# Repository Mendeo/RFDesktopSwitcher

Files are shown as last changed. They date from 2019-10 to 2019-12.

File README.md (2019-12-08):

# RF Desktop Switcher

Это проект устройства, которое переключает экран рабочего стола в Windows 10 по сигналу с датчика движения. Связь между датчиком движения и компьютером беспроводная.

## Проект включает в себя:
##### Передающая часть
* Схема устройства.
* Печатная плата.
* Прошивка микроконтроллера, управляющего передающей частью.

##### Приёмная чать
* Прошивку Arduino.
* 3D модель корпуса готового устройства, подключаемого к компьютеру.

##### Программное обеспечение
* Программа для Windows 10, которая соединяется с подключенным устройствои и осуществляет по сигналу переключение рабочих столов.
* Эмулятор приёмного устройства (используется для разработки основной программы).

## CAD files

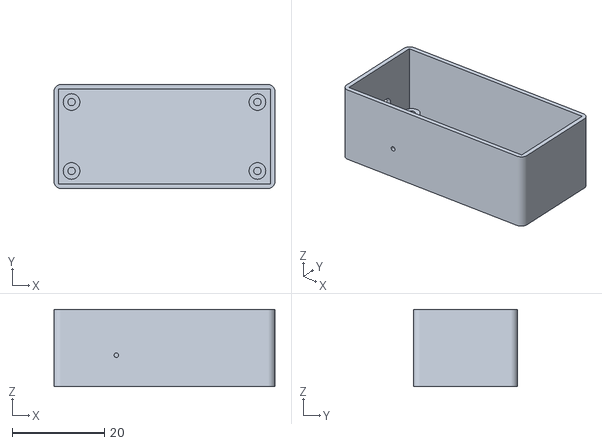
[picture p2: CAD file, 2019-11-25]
RX/Корпус/box.stl
47.8 x 22.5 x 16.7

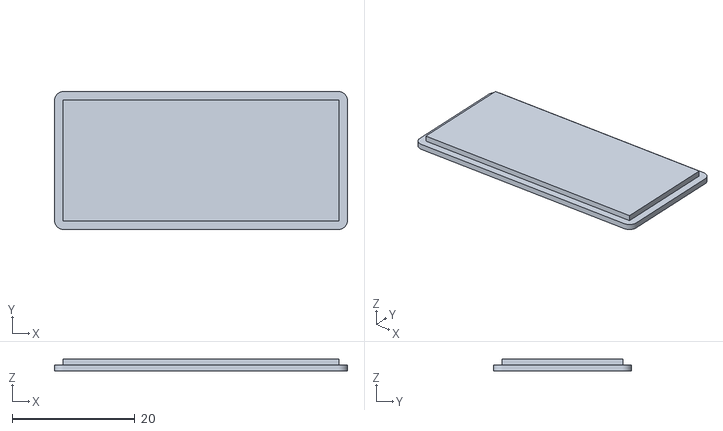
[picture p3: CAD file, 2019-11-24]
RX/Корпус/cap.stl
47.8 x 22.5 x 2.00

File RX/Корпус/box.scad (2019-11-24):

box(100, 70, 30, 2, 5, 2);
translate([25, 15, 0])
pillars(50, 40, 10, 20, 4, 0.8);
*translate([0, 0, 30])
cap(100, 70, 2, 5, 3, 5, 2, 0.4);



module box(L, W, HBox, T, extPinRad, intPinRad, needInternalPins)
{
	difference()
	{
		union()
		{
			difference()
			{
				cube([L, W, HBox]);
				translate([T, T, T])
				cube([L - 2 * T, W - 2 * T, HBox]);
			}
			for (edge = [0 : 3]) pinEdgePlacer(edge, HBox, extPinRad, intPinRad, 0, T, 0, L, W, 0, 0); //Цилиндр по четырём углам
		}
		//Вырез оставшихся треугольников по четырём углам.
		for (edge = [0 : 3]) excessTriangle(edge, HBox, extPinRad, L, W);
		if (!needInternalPins)
		{
			//Вырез внутренних цилиндров по четырём углам.
			for(edge = [0 : 3]) cutInternalPins(edge, HBox, extPinRad, L, W, T);
		}
	}
}

module cap(L, W, T, HCapExt, HCapInt, extPinRad, intPinRad, capGap, boxHasInternalPins)
{
	difference()
	{
		difference()
		{
			union()
			{
				cube([L, W, HCapExt]);
			}
			for (edge = [0 : 3]) pinEdgePlacer(edge, HCapExt, extPinRad, intPinRad, 0, 0, 2, L, W, 0, 0); //Цилиндр по четырём углам
		}
		for (edge = [0 : 3]) excessTriangle(edge, HCapExt, extPinRad, L, W); //Вырез оставшихся треугольников по четырём углам.
	}
	difference()
	{
		translate([T + capGap, T + capGap, -HCapInt]) //Часть крышки, что заходит внутрь.
		cube([L - 2 * (T + capGap), W - 2 * (T + capGap), HCapInt]);
		if (boxHasInternalPins)
		{
			translate([0, 0, -HCapInt])
			for (edge = [0 : 3]) pinEdgePlacer(edge, HCapInt, extPinRad + capGap, 0, 0, 0, 1, L, W, 0, 0);
		}
	}
}

//Размещает пины (цилиндры с дыркой) по 4-м сторонам прямоугольника, заданного width, length, x, y. Угол задаётся edge.
//Размеры прямоугольника соответствуют краям цилиндров с радиусом er.
//Если радиуса er не достаточно, то можно увеличить его добавкой addToExtRad. Это увеличит внешний радиус без смещения центра пина.
module pinEdgePlacer(edge, hh, er, ir, addToExtRad, holeFromBottom, pinSelect, length, width, deltaX, deltaY)
{
	x = (edge == 1 || edge == 3) ? length - er : er;
	y = (edge == 2 || edge == 3) ? width - er : er;
	translate([x + deltaX, y + deltaY, 0])
	pin(pinSelect, er + addToExtRad, ir, hh, holeFromBottom);
}

//Пины для прикручивания (цилиндры с дыркой).
module pin(pinSelect, er, ir, hh, holeFromBottom) //pinSelect: 0 - цилиндр с дыркой, 1 - только цилиндр, 2 - только дырка в виде цилиндра.
{
	difference()
	{
		if (pinSelect == 0 || pinSelect == 1) cylinder(r = er, h = hh);
		if (pinSelect == 0 || pinSelect == 2)
		{
			translate([0, 0, holeFromBottom])
			cylinder(r = ir, h = hh - holeFromBottom);
		}
	}
}

//Вырез оставшихся треугольников по четырём углам.
module excessTriangle(edge, hh, er, L, W)
{
	xCyl = (edge == 1 || edge == 3) ? L - er : er;
	yCyl = (edge == 2 || edge == 3) ? W - er : er;
	xCube = (edge == 1 || edge == 3) ? L - er: 0;
	yCube = (edge == 2 || edge == 3) ? W - er : 0;
	difference()
	{
		translate([xCube, yCube, 0])
		cube([er, er, hh]);
		translate([xCyl, yCyl, 0])
		cylinder(r = er, h = hh);
	}
}

module cutInternalPins(edge, hh, er, L, W, T)
{
	xCube = (edge == 1 || edge == 3) ? L - T - er * 2 : T;
	yCube = (edge == 2 || edge == 3) ? W - T - er * 2 : T;
	translate([xCube, yCube, T])
	cube([er * 2, er * 2, hh]);
}

//Столбики с вырезом - держалки для чего-либо.
module pillar(wPillar, hPillar, hFromPlate, cut)
{
	difference()
	{
		cube([wPillar, wPillar, hPillar]);
		translate([wPillar * (1 - cut), wPillar * (1 - cut), hFromPlate])
		cube([wPillar * cut, wPillar * cut, hPillar - hFromPlate]);
	}
}

//Размещает столбики-держалки по четырём углам.
module pillars(L, W, wPillar, hPillar, hFromPlate, cut) //W - по x ширина, L - по y длина - расстояние между стойками
{
	delta = (1 - cut) * wPillar;
	render()
	for (edge = [0 : 3])
	{
		x = (edge == 1 || edge == 3) ? L + delta : 0 - delta;
		y = (edge == 2 || edge == 3) ? W + delta : 0 - delta;
		alpha = (edge == 0 ? 0 : (edge == 1 ? 90 : (edge == 2 ? -90 : 180)));
		translate([x, y, 0])
		rotate([0, 0, alpha])
		pillar(wPillar, hPillar, hFromPlate, cut);
	}
}

//Делает скруглённые отверстия.
module roundedHole(L, W, H)
{
	linear_extrude(height = H)
	hull()
	{
		translate([W / 2, 0, 0])
		circle(d = W);
		translate([L - W / 2, 0, 0])
		circle(d = W);
	}
}

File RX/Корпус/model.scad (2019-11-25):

use <box.scad>

$fn = 250;

devL = 43.8;
devW = 18.5;
devH = 12.2; //От кромки платы ардуино до верхушки дросселя на приёмнике.
extraSpace = 2;
T = 1;

HPin = 2.5;
intPinRad = 0.8;
arduinoThiknesToHole = 1;

hCapInt = T;
hCapExt = T;

usbL = 7.8;
usbW = 2.8;

arduinoPlateThiknes = 1.7;

boxEdgeRad = 1.5;

antennaD = 1;
XfromPlateEdgeToAntennaEdge = 13;
ZfromPlateEdgeToAntennaEdge = 2.8;

extPinRad = intPinRad + arduinoThiknesToHole;
addToExtPinRad = intPinRad + T - extPinRad;

L = devL + extraSpace + 2 * T;
W = devW + extraSpace + 2 * T;
H = HPin + T + devH + hCapInt;

render()
devBox();

*
translate([0, 0, hCapExt])
rotate([180, 0, 0])
render()
cap(L, W, T, hCapExt, hCapInt, boxEdgeRad, 0, 0.4, false);

module devBox()
{

	difference()
	{
		box(L, W, H, T, boxEdgeRad, 0, false);
		//Отверстие под микро USB.
		translate([0, (W - usbL) / 2, usbW / 2 + T + HPin + arduinoPlateThiknes + 0.1])
		rotate([90, 0, 90])
		roundedHole(usbL, usbW, T);
		for (edge = [0 : 3]) pinEdgePlacer(edge, HPin + T, extPinRad, intPinRad, addToExtPinRad, 0, 2, devL, devW, T + extraSpace / 2, T + extraSpace / 2); //Делаем дырки насквозь, чтобы потом они оказаись в пинах.
		//Отверстие под антенну.
		translate([antennaD / 2 + XfromPlateEdgeToAntennaEdge, T, antennaD / 2 + T + HPin + ZfromPlateEdgeToAntennaEdge])
		rotate([90, 0, 0])
		cylinder(h = T, d = antennaD);
	}
	for (edge = [0 : 3]) pinEdgePlacer(edge, HPin + T, extPinRad, intPinRad, addToExtPinRad, 0.4, 0, devL, devW, T + extraSpace / 2, T + extraSpace / 2);
}

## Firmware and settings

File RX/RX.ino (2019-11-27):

#define RX_PIN 2
#define ERROR_VALUE 2
#define COMMAND_READY 'r'
#define COMMAND_IN_WORK 'w'
#define COMMAND_ANSWER 'o'
#define COMMAND_FIRE 'f'
#define COMMAND_DISCONNECT 'd'
#define COMMAND_COMP_ALIVE 'a'
#define SCAN_TIMEOUT 100
#define CHECK_DEVICE_TIMEOUT 1000
#define CHECK_COMP_ALIVE_TIMEOUT 2000
#define PAUSE_TIME 8000

const uint8_t RX_DATA[] = {12, 43, 29, 42, 24};
unsigned long _sysTime;
unsigned long _lastInWorkSend = 0;
unsigned long _lastFireSend = 0;
unsigned long _startPauseTime = 0;
unsigned long _lastCompAliveReceived = 0;
bool _isReadyStatus = true;
bool _needWaitPause = false;

volatile unsigned long _RXCurrentTime = 0;
volatile unsigned long _RXPreviousTime = 0;
volatile unsigned long _pulseDuration = 0;
volatile uint8_t _rxCounter = 0;
volatile bool _isFire = false;

void setup()
{
  pinMode(RX_PIN, INPUT);
  Serial.begin(115200);
}

void onPulse()
{
  _RXCurrentTime = millis();
  _pulseDuration = _RXCurrentTime - _RXPreviousTime;
  _RXPreviousTime = _RXCurrentTime;
  if (!(digitalRead(RX_PIN) ^ (_rxCounter % 2)) && _pulseDuration >= RX_DATA[_rxCounter] - ERROR_VALUE && _pulseDuration <= RX_DATA[_rxCounter] + ERROR_VALUE)
  {
    _rxCounter++;
  }
  else
  {
    _rxCounter = 0;
  }
  if (_rxCounter == sizeof(RX_DATA))
  {
    _isFire = true;
    _rxCounter = 0;
  }
}

void loop()
{
  //Режим ожидания подключения.
  if (_isReadyStatus)
  {
    while (true)
    {
      if (Serial.available())
      {
        if (Serial.read() == COMMAND_ANSWER)
        {
          _isReadyStatus = false;
          Serial.flush();
          attachInterrupt(digitalPinToInterrupt(RX_PIN), onPulse, CHANGE);
          break;
        }
      }
      Serial.write(COMMAND_READY);
      delay(SCAN_TIMEOUT);
    }
    _lastCompAliveReceived = millis();
  }
  _sysTime = millis();
  //Отправка символа работы.
  if (_sysTime - _lastInWorkSend >= CHECK_DEVICE_TIMEOUT)
  {
    _lastInWorkSend = _sysTime;
    Serial.write(COMMAND_IN_WORK);
  }
  //Если пришло сообщение.
  if (Serial.available())
  {
    char data = Serial.read();
    Serial.flush();
    if (data == COMMAND_DISCONNECT)
    {
      disconnect();
    }
    else if (data == COMMAND_COMP_ALIVE)
    {
      _lastCompAliveReceived = _sysTime;
    }
  }
  if (_sysTime - _lastCompAliveReceived > CHECK_COMP_ALIVE_TIMEOUT) disconnect();
  if (_isFire)
  {
    _isFire = false;
    detachInterrupt(digitalPinToInterrupt(RX_PIN)); //Отключаем перывания на время паузы
    _needWaitPause = true;
    _startPauseTime = _sysTime;
    Serial.write(COMMAND_FIRE);
  }
  if (_needWaitPause && _sysTime - _startPauseTime >= PAUSE_TIME) //Ждём PAUSE_TIME милисекунд после события _isFire.
  {
    _needWaitPause = false;
    attachInterrupt(digitalPinToInterrupt(RX_PIN), onPulse, CHANGE);
  }
}

inline void disconnect()
{
  detachInterrupt(digitalPinToInterrupt(RX_PIN));
  _isReadyStatus = true;
}

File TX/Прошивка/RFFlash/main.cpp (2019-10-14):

/*
 * RFFlash.cpp
 *
 * Created: 09.10.2019 14:12:09
 * Author : Александр Меняйло
 */ 

#define F_CPU 1200000UL

#include <avr/io.h>
#include <avr/interrupt.h>
#include <avr/sleep.h>
#include <util/delay.h>
#include <avr/wdt.h>

#define TX_PAUSE 50
#define TX_REPEAT 5
#define TX_PIN PORTB0
#define TX_POWER PORTB4
//#define TX_SIZE 5

const uint8_t TX_DATA[] = {12, 43, 29, 42, 24};
volatile bool _hasSignal = false;  
volatile bool _txEnable = false;

ISR(INT0_vect)
{
	_hasSignal = true;
}

ISR (WDT_vect)
{
	_txEnable = true;
	_hasSignal = false;
	//WDTCR |= (1 << WDTIE); //Включаем прерывание от WDT.
}

inline void delay(uint8_t t)
{
	while(t--)
	{
		_delay_ms(1);
	}
}

inline void send()
{
	PORTB |= (1 << TX_POWER);
	_delay_ms(50); //Время на включение передатчика.
	for (unsigned int i = 0; i < TX_REPEAT; i++)
	{
		for (unsigned int j = 0; j < sizeof(TX_DATA); j++)
		{
			PORTB ^= (1 << TX_PIN);
			delay(TX_DATA[j]);
		}
		PORTB ^= (1 << TX_PIN);
		_delay_ms(TX_PAUSE);
	}
	PORTB &= ~(1 << TX_POWER);
}

inline void sleep()
{
	PORTB &= ~(1 << TX_PIN); //Выключаем TX_PIN.
	//PORTB &= ~(1 << TX_POWER); //Выключаем TX_POWER.
	//Выключаем BOD на время сна по схеме из даташита.
	BODCR = (1 << BODS) | (1 << BODSE);
	BODCR = (1 << BODS);
	sleep_cpu(); //Включаем сон.
}

inline void wdt_start()
{
	wdt_reset();
	wdt_enable(WDTO_8S);
	WDTCR |= (1 << WDTIE); //Включаем прерывание от WDT.
}

int main(void)
{
	DDRB = (1 << TX_PIN) | (1 << TX_POWER); //Включаем TX_PIN и TX_POWER на выход, остальные на вход.
	GIMSK = (1 << INT0); //Включаем прерывания на INT0 (PB1).
	MCUCR &= ~(1 << ISC00) & ~(1 << ISC01); //Настраиваем прерывание по низкому уровню.
	//Выключаем ADC.
	ADCSRA &= ~(1 << ADEN);
	PRR |= (1 << PRADC);	
	sei(); //Разрешаем прерывания.
	//Нстраиваем WDT
	wdt_start();
	set_sleep_mode(SLEEP_MODE_PWR_DOWN); //Нстраиваем режим сна.
	sleep_enable(); //Разрешаем сон в приниципе.

	while (1)
	{
		if (_hasSignal && _txEnable) 
		{
			cli();
			_hasSignal = false;
			_txEnable = false;
			send();
			wdt_start(); //Взводим WDT.
			sei();
		}
		if (_txEnable) wdt_disable(); //Выключаем WDT для экономии энергии во время сна.
		sleep();
	}
}

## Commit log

2019-10-14 Решил создать репозиторий для проекта.
2019-10-14 Сделал программу, которая эмулирует разрабатываемое устройство на com порте. Программа шлёт свои данные в com1. А при помощи Virtual Serial Port Tools эти данные перенаправляются на com2, которые я б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
2019-10-14 Добавил вывод сообщений о присутствии устройства в отдельный поток. Работаю с этими сообщениями в основной программе.
2019-10-14 Добавил перезапуск программы эмулятора по команде.
2019-10-14 Эмулятор переделал на SyncLock вместо мьютексов для синхронизации потоков.
2019-10-14 Немного переименовал папку с эмулятором, чтобы было понятней.
2019-10-15 Небольшие исправления, ловля багов.
2019-10-15 Добавил ввод номера порта.
2019-10-15 Настроил закрытие программы после закрытия окна.
2019-10-16 Пытаюсь программно переключать рабочие столы, пока не получается.
2019-10-16 Ещё попробовал некоторые идеи по переключению рабочих столов.
2019-10-16 Сделал переключение рабочих столов при помощи виртуального нажатия клавиш.
2019-10-16 Переписал название функции на оригинальное из winApi.
2019-10-16 Вернул программу в рабочее состояние.
2019-10-16 Работаю с иконкой в трее.
2019-10-16 Добавил контекстное меню к основной программе. Пытался переделать эмулятор, но не вышло.
2019-10-17 Переделал эмулятор, чтобы он ещё перезапускался не только по "reboot" из консоли, но и по команде из com порта. Всё работает хорошо, кроме одной вещи: т.к. я не могу завершить поток, который читает и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
2019-10-17 Убрал лишний ненужный поток в эмуляторе. Исправил ошибку в основной программе, когда был доступ меню из не главного потока.
2019-10-17 Работа над эмулятором. Если в буфере com порта есть данные, то они передавались в программу тогда, когда это не нужно. Теперь очищаем буфер.
2019-10-17 Перестал прерывать поток, который читает с консоли, теперь писать в консоль можно всегда.
2019-10-17 В эмуляторе исправил небольшую ошибку. В основной программе сделал окно, в котором пользователь может перезапускать отслеживание открытия дверей. Но это окно пока не работает)
2019-10-17 Настроил в главной программе работу окна возобновления мониторинга.
2019-10-17 Улучшил вывод сообщений в эмултяторе.
2019-10-17 Всякие улучшения. Попробовал закрывать окно по нажатию "разъединить" в трее.
2019-10-17 Сделал закрытие окна по разрыву соединения. Испраивл ошибку, когда программа не подключалась к устройству, т.к. в com порте уже висели какие-то левые данные.
2019-10-17 Переставил элементы меню местами.
2019-10-17 Скрыл главную форму. Начал переводить на безформенный запуск.
2019-10-18 Решил оставить на формах. Сделал некоторые переименования.
2019-10-18 Улучшил нотификацию.
2019-10-18 Сделал смену иконок в зависимости отситуации. И улучшил работу с окном RefreshWatch.
2019-10-18 Сделал вызов разрыва соединения из RefreshWatch по событию. Также исправил ошибку - события второй раз не всплывали. Сделал их Shared.
2019-10-19 Написал код для Ардуино.
2019-10-19 Добавил тестовый логотип в основную программу. Он теперь отображется при запуске. В скетч ардуино добавил комментарий.
2019-10-19 Поставил значок на исполняемый файл программы.
2019-10-19 Переделал код в Ардуино через прерывания, т.к. иначе время точно не измереяется и сигнал не определяется.
2019-10-19 Сделал динамическое включение и отключение прерывания. После расшифровки сообщения о возникновении события, повторные сообщения не принимаются в течение восьми секунд. Это сделал, чтобы он в Serial с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
2019-10-19 Вывел окно перезапуска мониторинга поверх всех окон.
2019-10-19 Перевёл на младший .net
2019-10-19 Убрал ненужную dll.
2019-10-20 Добавил иконку в конструкторе в трей, т.к. ненадолго она может появится при запуске программы.
2019-11-14 Немного исправил код приёмника для лучшей читабельности.
    [RX.ino]
2019-11-14 Добавил x64
2019-11-14 Исправил ошибку на плате передатчика.
2019-11-16 Проводил настройки оптимизации компиляции в AtmeStudio.
2019-11-17 Добавил на плату передатчика схему укорочения сигнала от PIR сенсора. Вместо 2.5 секунд теперь будет около 90 мс.
2019-11-24 Изменил программму-драйвер так. чтобы переключение рабочих столов осуществлялось строго после того, как появится окно для возобновления отслеживания. Иначе иногда переключение не срабатывало.
2019-11-24 Программа-драйвер. Изменил событие, которое отвечает за то, что окно RefreshWatch отобразилось.
2019-11-24 Добавил интервал времени между нажатиями клавиш для переключения рабочих столов.
2019-11-24 Добавил модель для корпуса приёмника.
    [box.scad, box.stl, cap.stl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]
2019-11-24 Изменил конфигурацию папкок.
2019-11-24 Программа-драйвер. Добавил интервалы времени между нажатиями кнопок. Возможно в этом была причина, что не всегда срабатывает переключение рабочих столов.
2019-11-24 Добавил скрипт для UoPilot, который в Device Emulator отправляет "f" через заданное в скрипте время.
2019-11-25 Немного исправил модель корпуса: сделал пины для держания ардуино уже.
    [box.stl, model.scad]
2019-11-26 Добавил в исключение папку с фотографиями.
2019-11-27 Добавил в эмулятор приём сигнала от компьютера, о том, что ком присутствует на линии.
2019-11-27 Добавил в программу для Windows посылку сообщений каждую секунду, чтобы приёмник знал, что программа всё ещё работает.
2019-11-27 В прошивку приёмника добавил получение сигналов от компа, что приложение работает и комп не завис.
2019-11-27 Немного исправил время проверки сигналов от компьютера в прошивке приёмника.
    [RX.ino]
2019-11-27 Небольшие улучшения в читаемости кода программы-драйвера.
2019-11-27 Исправлены некоторые ошибке в программе-драйвере
2019-12-03 Добавил переподключение программы в случае, если комп завис, а потом отвис.
2019-12-03 Добавил схему для передатчика.
    [Схема.sch]
2019-12-08 Добавил простое README.md.
2019-12-08 Удалил лишний резистор с печатной платы, т.к. при работе с датчиком движения он не нужен.
2019-12-08 Исправил README.md так, чтобы читалось на github'е.
2019-12-08 Добавил описание в README.md
